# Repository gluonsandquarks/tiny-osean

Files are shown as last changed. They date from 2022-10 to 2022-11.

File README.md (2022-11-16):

# Tiny Osean

Minimal PCB badge based around the ATTiny1616 and a CR2032 battery.

Board in action

This PCB mainly focuses on the capabilities of the manufacturing process to create a non standard PCB with more intricate shapes and patterns. At the end of the day this is more of a wearable/toy PCB rather than a complex application/platform.

DISCLAIMER: I'm not the creator of the artwork, [@oseanworld](https://twitter.com/OseanWorld) is the artist behind the character in the badge.

## Hardware

The board is pretty basic. In total there are 16 components:

- 1 x ATTiny1616: Low power microcontroller.
- 1 x 100nF bypass capacitor.
- 1 x 1uF bypass capacitor.
- 1 x push button.
- 1 x 10k ohm resistor
- 8 x 10 ohm resistors.
- 2 x yellow LEDs.
- 1 x CR2032 battery holder.

If you know what you're doing you could modify the design and add more LEDs, remove bypass caps (they aren't totally necessary with the ATTiny series), etc.

The board has three terminals, two of them are to give power to the board (the _+_ and _-_ pins) and the _D_ terminal is connected to the _PA0_ pin on the ATTiny. This enables the device to be programmed via UPDI.

The design was done through the [svg2shenzhen](https://github.com/badgeek/svg2shenzhen) addon for Inkscape. The _nudeki.svg_ file contains all the layers data for the board. The electrical and PCB design was done in [KiCad v6](https://www.kicad.org/).

Other than that, I think that's it. It's a pretty bare bones design so make of it what you wish. Also the _gerber/_ and _assembly/_ directories contain the necessary files to order and assemble the boards at [jlcpcb.com](https://jlcpcb.com/).

One side note is that the LEDs are mounted in such a way that the light is emitted from the board. The ideal way to mount them is facing down so that the light can shine through the FR-4 and illuminate the eyes more uniformly. With the right tools it's possible to unmount the LEDs and reverse them.

## Firmware

The firmware of the board is located under _firmware/main/_. It contains a simple Arduino sketch but it has the following dependencies:

- [megaTinyCore](https://github.com/SpenceKonde/megaTinyCore): Arduino wrapper for tinyAVR 0/1/2 chips.
- [jtag2updi](https://github.com/SpenceKonde/jtag2updi): UPDI programmer software for Arduino.

Install these dependencies and you'll be able to use an Arduino UNO or similar boards as programmers for the _tiny-osean_ board. If you have any problem with the installation procedure or wiring try looking at [this video](https://www.youtube.com/watch?v=AL9vK_xMt4E).

The _main.ino_ file contains a handful of lighting modes for the board and tries to document them as needed. The programming of the LEDs is pretty straight forward and user friendly, just beware of your logic inside the functions so that the interrupt signal gets processed in a relatively fast way to reduce latency.

## Design Images

### Front View

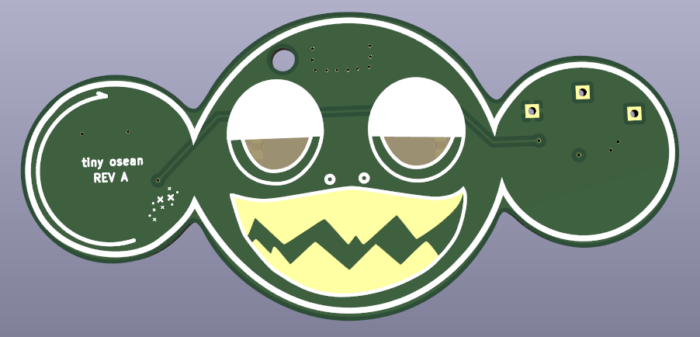
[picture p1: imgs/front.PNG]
3D Front View


### Back View

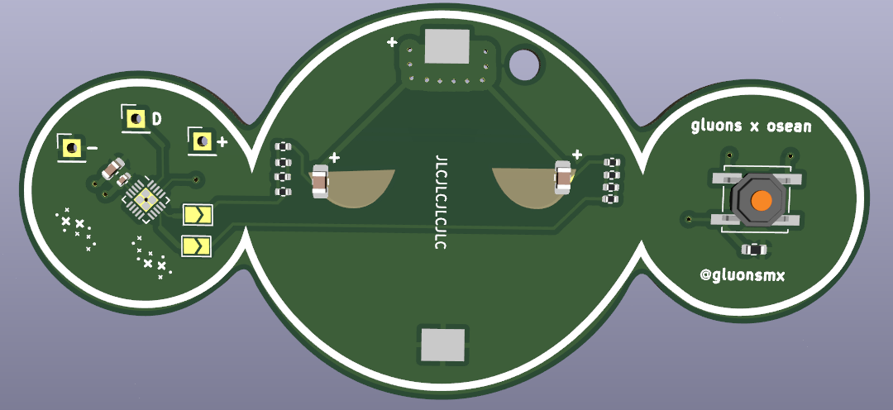
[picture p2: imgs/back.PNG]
3D Back View


### Layers

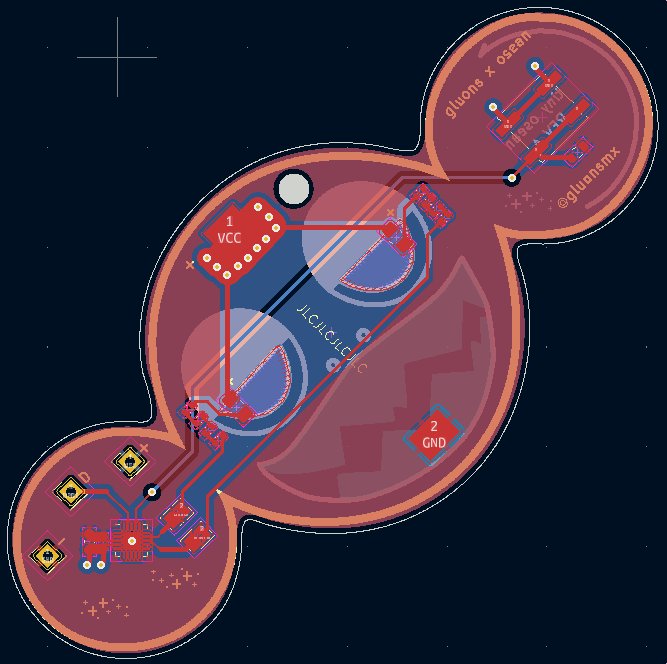
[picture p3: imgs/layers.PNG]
Layers


### Schematic

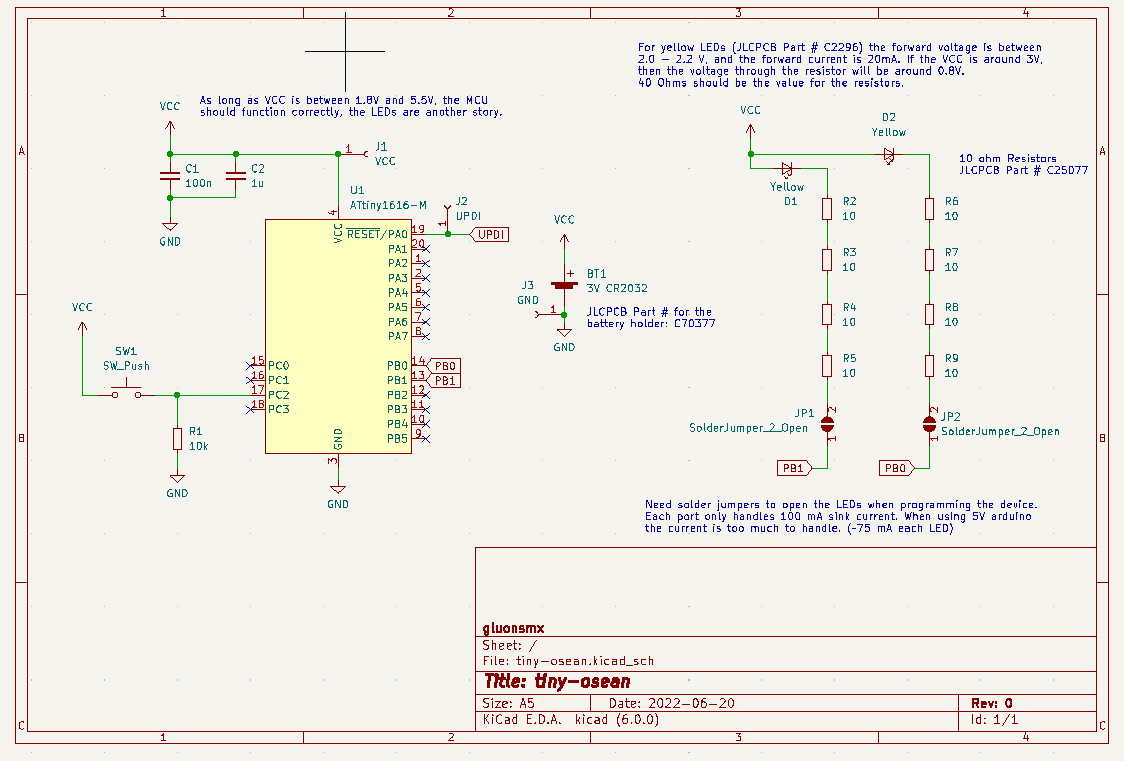
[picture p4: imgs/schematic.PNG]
Schematic


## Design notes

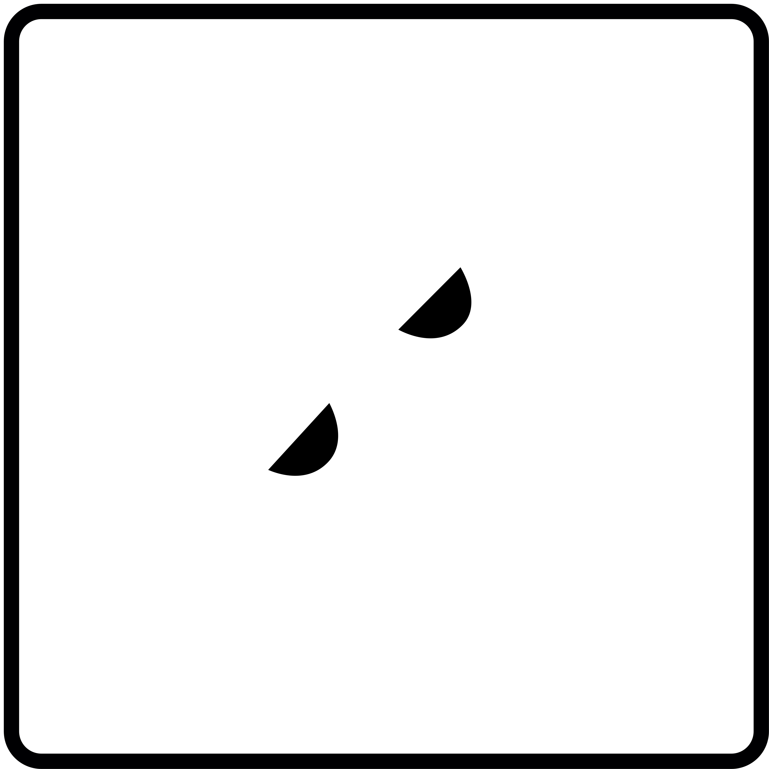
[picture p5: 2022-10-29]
rev b/100mm-osean/.svg2shenzhen-cache/images/F.Mask_g23.png

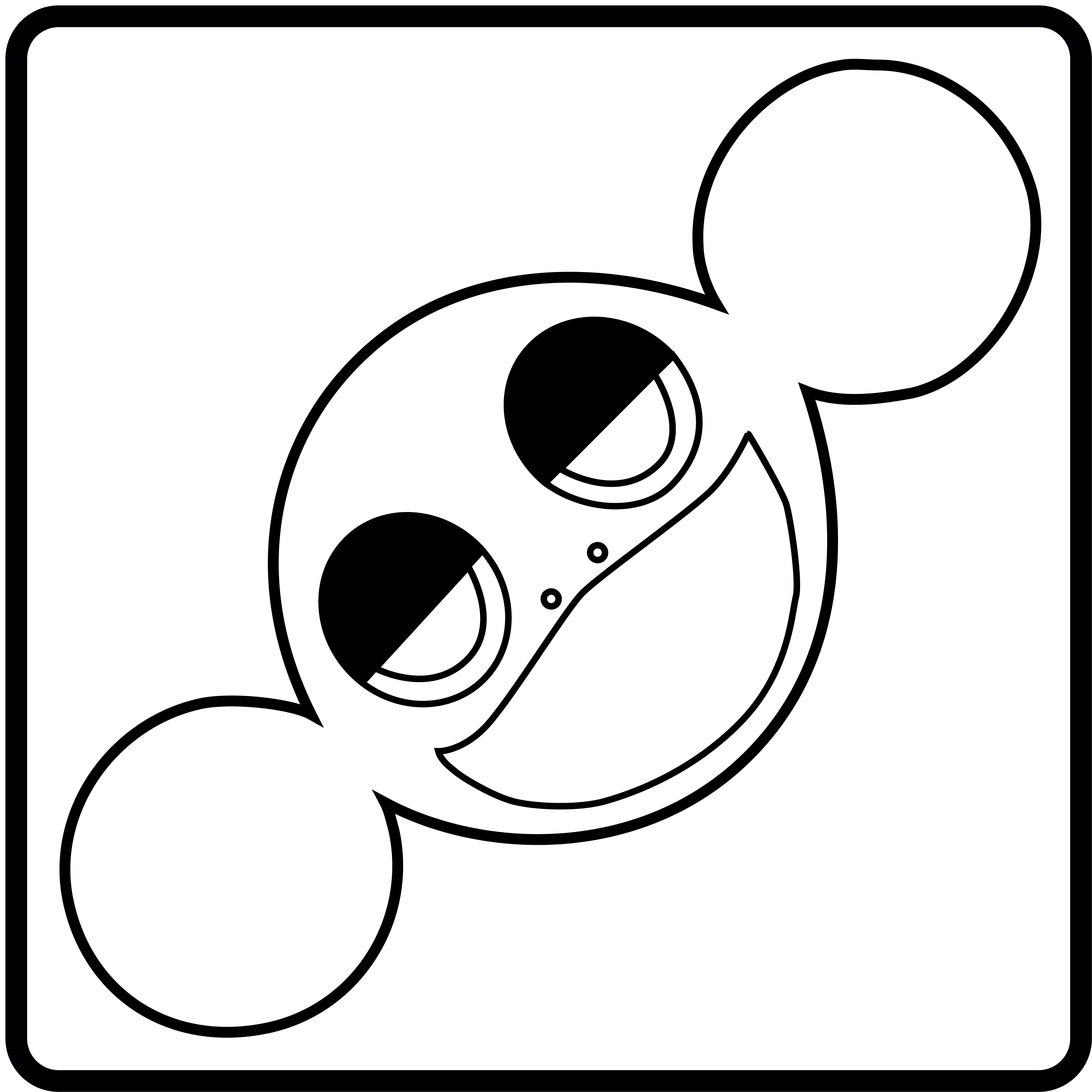
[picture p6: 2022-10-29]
rev b/100mm-osean/.svg2shenzhen-cache/images/B.SilkS_g31.png

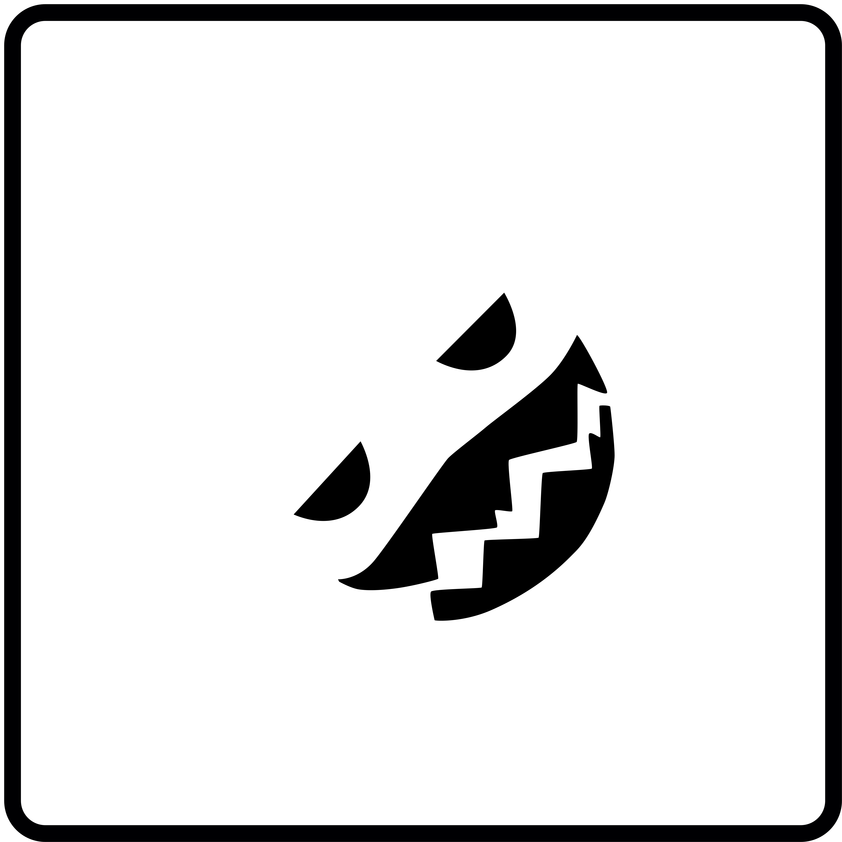
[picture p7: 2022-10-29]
rev b/100mm-osean/.svg2shenzhen-cache/images/B.Mask_g29.png

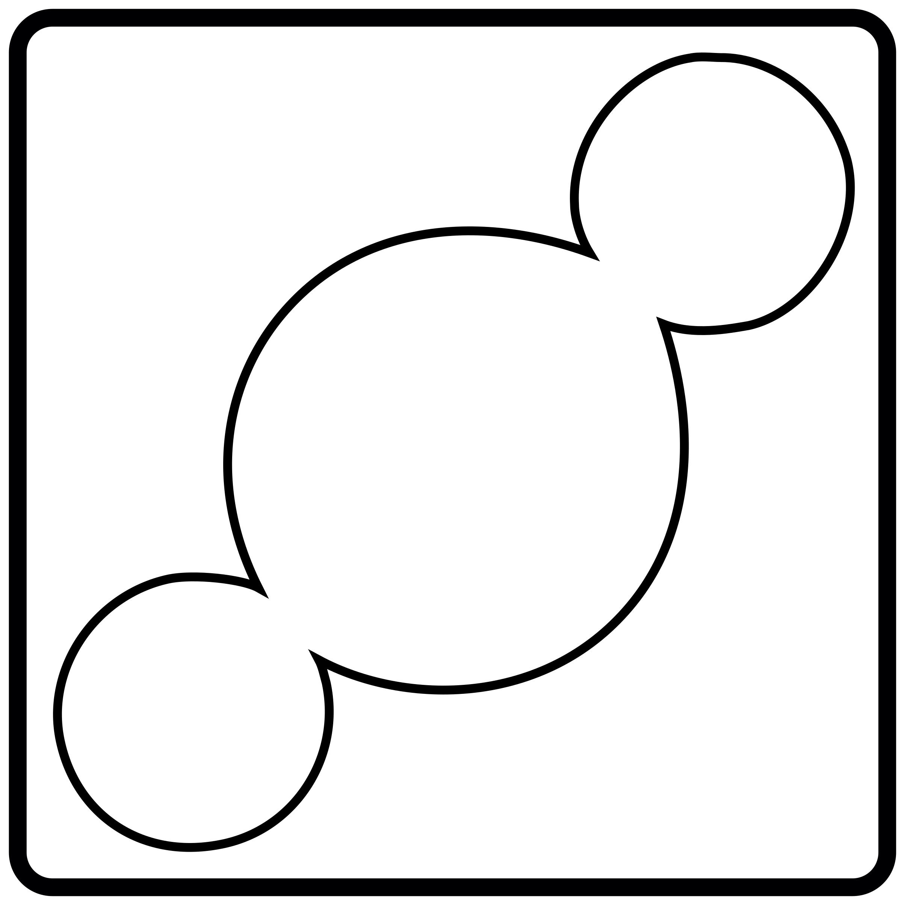
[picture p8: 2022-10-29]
rev b/tiny-osean-footprint/.svg2shenzhen-cache/images/F.SilkS_g25.png

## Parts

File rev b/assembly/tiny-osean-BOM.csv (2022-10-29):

Comment | Designator | Footprint | LCSC
3V CR2032 | BT1 | tiny-osean:CR2032 Holder | C70377
100n | C1 | Capacitor_SMD:C_0402_1005Metric | C307331
1u | C2 | Capacitor_SMD:C_0603_1608Metric | C15849
Yellow | D1,D2 | Capacitor_SMD:C_0805_2012Metric_Pad1.18x1.45mm_HandSolder | C2296
VCC | J1 | Connector_PinHeader_2.54mm:PinHeader_1x01_P2.54mm_Vertical
UPDI | J2 | Connector_PinHeader_2.54mm:PinHeader_1x01_P2.54mm_Vertical
GND | J3 | Connector_PinHeader_2.54mm:PinHeader_1x01_P2.54mm_Vertical
SolderJumper_2_Open | JP1,JP2 | Jumper:SolderJumper-2_P1.3mm_Open_TrianglePad1.0x1.5mm
10k | R1 | Resistor_SMD:R_0603_1608Metric | C25804
10 | R2,R3,R4,R5,R6,R7,R8,R9 | Resistor_SMD:R_0402_1005Metric | C25077
SW_Push | SW1 | Button_Switch_SMD:SW_Push_1P1T_NO_CK_KSC6xxJ | C318884
ATtiny1616-M | U1 | Package_DFN_QFN:VQFN-20-1EP_3x3mm_P0.4mm_EP1.7x1.7mm | C507118

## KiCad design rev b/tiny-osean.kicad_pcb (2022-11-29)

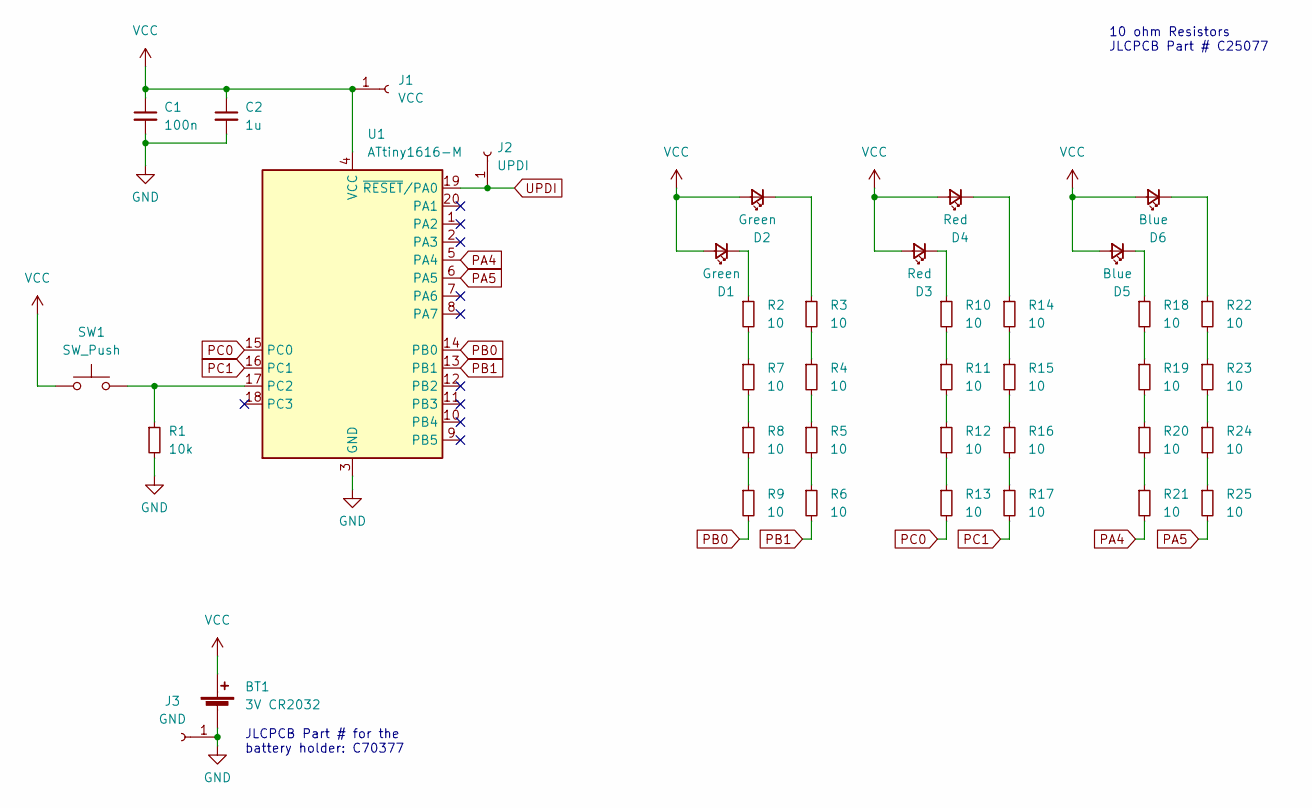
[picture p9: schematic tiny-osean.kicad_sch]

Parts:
BT1: 3V CR2032; CR2032 Holder; LCSC C70377
C1: 100n; C_0402_1005Metric; LCSC C307331
C2: 1u; C_0603_1608Metric; LCSC C15849
D1, D2: Green; C_0805_2012Metric_Pad1.18x1.45mm_HandSolder; LCSC C2296
D3, D4: Red; C_0805_2012Metric_Pad1.18x1.45mm_HandSolder; LCSC C2296
D5, D6: Blue; C_0805_2012Metric_Pad1.18x1.45mm_HandSolder; LCSC C2296
J1: VCC; PinHeader_1x01_P2.54mm_Vertical
J2: UPDI; PinHeader_1x01_P2.54mm_Vertical
J3: GND; PinHeader_1x01_P2.54mm_Vertical
R1: 10k; R_0603_1608Metric; LCSC C25804
R2, R3, R4, R5, R6, R7, R8, R9, R10, R11, R12, R13, R14, R15, R16, R17, R18, R19, R20, R21, R22, R23, R24, R25: 10; R_0402_1005Metric; LCSC C25077
SW1: SW_Push; SW_Push_1P1T_NO_CK_KSC6xxJ; LCSC C318884
U1: ATtiny1616-M; VQFN-20-1EP_3x3mm_P0.4mm_EP1.7x1.7mm; LCSC C507118

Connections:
GND: BT1.2 (-), C1.2, C2.2, J3.1, R1.2, U1.3 (GND), U1.21 (GND)
unnamed: D1.1 (K), R2.1
unnamed: D2.1 (K), R3.1
unnamed: D3.1 (K), R10.1
unnamed: D4.1 (K), R14.1
unnamed: D5.1 (K), R18.1
unnamed: D6.1 (K), R22.1
unnamed: R1.1, SW1.2, U1.17 (PC2)
unnamed: R3.2, R4.1
unnamed: R4.2, R5.1
unnamed: R5.2, R6.1
unnamed: R2.2, R7.1
unnamed: R7.2, R8.1
unnamed: R8.2, R9.1
unnamed: R10.2, R11.1
unnamed: R11.2, R12.1
unnamed: R12.2, R13.1
unnamed: R14.2, R15.1
unnamed: R15.2, R16.1
unnamed: R16.2, R17.1
unnamed: R18.2, R19.1
unnamed: R19.2, R20.1
unnamed: R20.2, R21.1
unnamed: R22.2, R23.1
unnamed: R23.2, R24.1
unnamed: R24.2, R25.1
PA4: R21.2, U1.5 (PA4)
PA5: R25.2, U1.6 (PA5)
PB0: R9.2, U1.14 (PB0)
PB1: R6.2, U1.13 (PB1)
PC0: R13.2, U1.15 (PC0)
PC1: R17.2, U1.16 (PC1)
UPDI: J2.1, U1.19 (~RESET/PA0)
VCC: BT1.1 (+), C1.1, C2.1, D1.2 (A), D2.2 (A), D3.2 (A), D4.2 (A), D5.2 (A), D6.2 (A), J1.1, SW1.1, U1.4 (VCC)

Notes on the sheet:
10 ohm Resistors JLCPCB Part # C25077
JLCPCB Part # for the battery holder: C70377

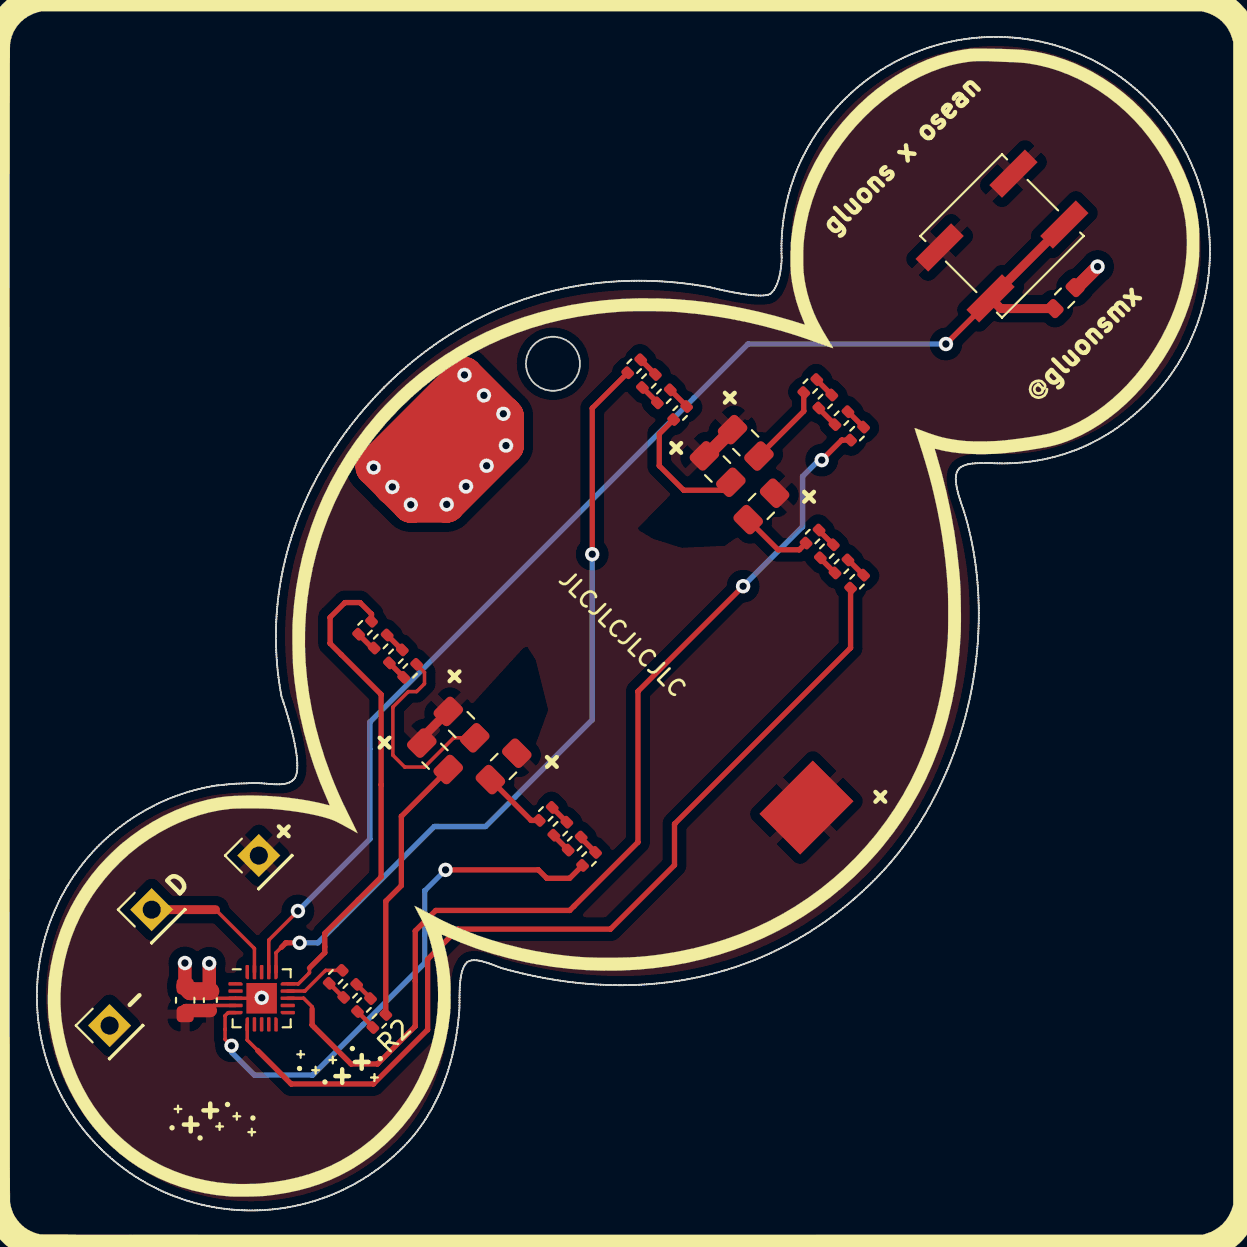
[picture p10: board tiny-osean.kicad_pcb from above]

Board: 2 copper layers, 65.2 x 65.2 mm, 40 parts (0 on the bottom side), 34 nets.

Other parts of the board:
Ref**: Val**; tiny-osean-70

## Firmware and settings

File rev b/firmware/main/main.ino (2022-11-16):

/*
 * This file is part of the tiny-osean project, https://github.com/gluonsandquarks/tiny-osean
 * main.ino - main entry point describing the functionality of the board.
 * This file contains the main logic of the board.
 * 
 * The MIT License (MIT)
 *
 * Copyright (c) 2022 gluons.
 *
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
 * THE SOFTWARE IS PROVIDED "AS IS", WITHOUT WARRANTY OF ANY KIND, EXPRESS OR
 * IMPLIED, INCLUDING BUT NOT LIMITED TO THE WARRANTIES OF MERCHANTABILITY,
 * FITNESS FOR A PARTICULAR PURPOSE AND NONINFRINGEMENT. IN NO EVENT SHALL THE
 * AUTHORS OR COPYRIGHT HOLDERS BE LIABLE FOR ANY CLAIM, DAMAGES OR OTHER
 * LIABILITY, WHETHER IN AN ACTION OF CONTRACT, TORT OR OTHERWISE, ARISING FROM,
 * OUT OF OR IN CONNECTION WITH THE SOFTWARE OR THE USE OR OTHER DEALINGS IN THE
 * SOFTWARE.
 */

#include <avr/sleep.h>            // Power saving library

/* 
 * Pins PB1 and PB0 on the ATTiny1616 are PWM, so analogWrite() should work on them
 * More about how the megaTinyCore lib maps the arduino pins: https://github.com/SpenceKonde/megaTinyCore/blob/master/megaavr/extras/ATtiny_x16.md
 * More about the schematic/pinout of the tiny-osean board: https://github.com/gluonsandquarks/tiny-osean/blob/main/imgs/schematic.PNG
 */
#define LEFT_EYE      PIN_PB1     // PB1
#define RIGHT_EYE     PIN_PB0     // PB0
#define BUTTON        PIN_PC2     // PC2

enum State
{
  ON = 0,
  BREATH_LO,
  BREATH_MID,
  BREATH_HI,
  ALT_LO,
  ALT_MID,
  ALT_HI,
  RUSH,
  RAND_DELAY,
  SOS,
  SMOOTH,
  SLEEP,
  MAX_STATE
};

/* Global variables */
State stat = ON;

/* Forward declarations */
void on();
void breathing(int ms);
void alternating(int ms);
void rush(int ms);
void rand_delay();
void sos();
void smooth();


/* Interrupt Service Routines (ISRs) */
void on_press();
void go_to_sleep();


void on()
{
  digitalWrite(RIGHT_EYE, LOW);
  digitalWrite(LEFT_EYE, LOW);
}

/* Function definitions for the different light shows */

/*
 * @brief Light show that smoothly dims and lights the LEDs through PWM.
 * 
 * @param ms Delay in milliseconds
 * @return Void
 */
void breathing(int ms)
{
  State temp = stat;
  for (int i = 0; i < 256; i++)
  {
    if (temp != stat) { break; }
    analogWrite(RIGHT_EYE, i);
    analogWrite(LEFT_EYE, i);
    delay(ms);
  }
  for (int i = 0; i < 256; i++)
  {
    if (temp != stat) { break; }
    analogWrite(RIGHT_EYE, 255 - i);
    analogWrite(LEFT_EYE, 255 - i);
    delay(ms);
  }
}

/*
 * @brief Light show that alternates both LEDs on/off.
 * 
 * @param ms Delay in milliseconds
 * @return Void
 */
void alternating(int ms)
{
  digitalWrite(RIGHT_EYE, HIGH);
  digitalWrite(LEFT_EYE, LOW);
  delay(ms);
  digitalWrite(RIGHT_EYE, LOW);
  digitalWrite(LEFT_EYE, HIGH);
  delay(ms);
}

/*
 * @brief Light show that alternates both LEDs on/off from dim to bright.
 * 
 * @param ms Delay in milliseconds
 * @return Void
 */
void rush(int ms)
{
  State temp = stat;
  for (float i = 0; i < 128.0F; i += 2.5F)
  {
    if (i >= 64.0F) { i += 3.0F; }
    if (temp != stat) { break; }
    analogWrite(RIGHT_EYE, 255 - i);
    analogWrite(LEFT_EYE, 255);
    delay(ms);
    if (temp != stat) { break; }
    analogWrite(RIGHT_EYE, 255);
    analogWrite(LEFT_EYE, 255 - i);
    delay(ms);
  }
  
  for (int i = 0; i < 5; i++)
  {
    if (temp != stat) { break; }
    digitalWrite(RIGHT_EYE, LOW);
    digitalWrite(LEFT_EYE, HIGH);
    delay(ms * 2);
    if (temp != stat) { break; }
    digitalWrite(RIGHT_EYE, HIGH);
    digitalWrite(LEFT_EYE, LOW);
    delay(ms * 2);
  }

  digitalWrite(RIGHT_EYE, LOW);
  digitalWrite(LEFT_EYE, LOW);
}

/*
 * @brief Light show that lights each LED at random intervals.
 * 
 * @return Void
 */
void rand_delay()
{
  unsigned long timer_1 = 570;
  unsigned long last_timer_1 = 0;
  unsigned long timer_2 = 350;
  unsigned long last_timer_2 = 0;
  State temp = stat;
  while (temp == stat)
  {
    if (millis() - last_timer_1 >= timer_1)
    {
      float multiplier = random(6.0F);
      for (float i = 0; i < 256 * multiplier; i++)
      {
        if (temp != stat) { break ;}
        analogWrite(RIGHT_EYE, (i / multiplier));
      }
      last_timer_1 = millis() * random(500);
    }

    if (millis() - last_timer_2 >= timer_2)
    {
      float multiplier = random(6.0F);
      for (float i = 0; i < 256 * multiplier; i++)
      {
        if (temp != stat) { break; }
        analogWrite(LEFT_EYE, (i / multiplier));
      }
      last_timer_2 = millis() * random(500);
    }
  }
}

/*
 * @brief Light show that emits SOS in morse code.
 * 
 * @param ms Delay in milliseconds
 * @return Void
 */
void sos(int ms)
{
  State temp = stat;
  unsigned long timer = 400;
  unsigned long last_timer = 0;
  for (int i = 0; i < 3; i++)
  {
    if (temp != stat) { break; }
    digitalWrite(RIGHT_EYE, LOW);
    digitalWrite(LEFT_EYE, LOW);
    delay(ms);
    digitalWrite(RIGHT_EYE, HIGH);
    digitalWrite(LEFT_EYE, HIGH);
    delay(ms);
  }

  for (int i = 0; i < 3; i++)
  {
    if (temp != stat) { break; }
    digitalWrite(RIGHT_EYE, LOW);
    digitalWrite(LEFT_EYE, LOW);
    delay(ms * 2);
    digitalWrite(RIGHT_EYE, HIGH);
    digitalWrite(LEFT_EYE, HIGH);
    delay(ms * 2);
  }

  for (int i = 0; i < 3; i++)
  {
    if (temp != stat) { break; }
    digitalWrite(RIGHT_EYE, LOW);
    digitalWrite(LEFT_EYE, LOW);
    delay(ms);
    digitalWrite(RIGHT_EYE, HIGH);
    digitalWrite(LEFT_EYE, HIGH);
    delay(ms);
  }
  last_timer = millis();
  while (temp == stat)
  {
    if (millis() - last_timer >= timer)
    {
      last_timer = millis();
      break;
    }
  }
}

/*
 * @brief Light show that transitions smoothly between both LEDs on board.
 * 
 * @param ms Delay in milliseconds
 * @return Void
 */
void smooth(int ms)
{
  State temp = stat;
  int i = 0;
  int j = 0;

  for (i; i < 256; i++)
  {
    if (temp != stat) { break; }
    if (i > 32) { i += 30; }
    j = i - 8;
    if (j < 0) { j = 0; }
    analogWrite(RIGHT_EYE, 255 - i);
    analogWrite(LEFT_EYE, 255 - j);
    delay(ms);
  }

  i = 255;
  j = 255;
  for (i; i > 0; i--)
  {
    if (temp != stat) { break; }
    if (i > 32) { i -= 30; }
    j = i + 8;
    if (j > 255) { j = 255; }
    analogWrite(RIGHT_EYE, 255 - i);
    analogWrite(LEFT_EYE, 255 - j);
    delay(ms);
  }
  i = 0;
  analogWrite(RIGHT_EYE, 255 - i);
  j = 8;
  for (j; j >= 0; j--)
  {
    if (temp != stat) { break; }
    analogWrite(LEFT_EYE, 255 - j);
    delay(ms);
  }
}

/*
 * @brief ISR called when a button is pressed.
 * 
 * @return Void
 */
void on_press()
{
  stat = State(stat + 1);
  if (stat >= MAX_STATE) { stat = ON; }
}

/*
 * @brief Last mode of the device. Shuts down LEDs and goes to sleep.
 * 
 * @return Void
 */
void go_to_sleep()
{
  digitalWrite(RIGHT_EYE, HIGH);
  digitalWrite(LEFT_EYE, HIGH);
  set_sleep_mode(SLEEP_MODE_PWR_DOWN);
  sleep_enable();
  // TODO: research these parameters for the ATTiny1616. For some reason
  // these guys aren't defined for this MCU. Look into the avr/sleep.h implementation.
  //  byte adcsra = ADCSRA;                             // save ADCSRA
  //  ADCSRA &= ~_BV(ADEN);                             // disable ADC
  cli();                                                 // stop interrupts to ensure the BOD timed sequence executes as required
  //  byte mcucr1 = MCUCR | _BV(BODS) | _BV(BODSE);     //turn off the brown-out detector
  //  byte mcucr2 = mcucr1 & ~_BV(BODSE);
  //  MCUCR = mcucr1;
  //  MCUCR = mcucr2;
  sei();                                                // ensure interrupts enabled so we can wake up again
  sleep_cpu();                                          // go to sleep
  sleep_disable();                                      // wake up here
  //  ADCSRA = adcsra;                                  // restore ADCSRA
}

void setup()
{
  /* Initialize peripherals */
  pinMode(RIGHT_EYE, OUTPUT);
  pinMode(LEFT_EYE, OUTPUT);
  pinMode(BUTTON, INPUT);
  /* Disable floating pins */
  pinMode(PIN_PA1, INPUT_PULLUP);
  pinMode(PIN_PA2, INPUT_PULLUP);
  pinMode(PIN_PA3, INPUT_PULLUP);
  pinMode(PIN_PA4, INPUT_PULLUP);
  pinMode(PIN_PA5, INPUT_PULLUP);
  pinMode(PIN_PA6, INPUT_PULLUP);
  pinMode(PIN_PA7, INPUT_PULLUP);
  pinMode(PIN_PB2, INPUT_PULLUP);
  pinMode(PIN_PB3, INPUT_PULLUP);
  pinMode(PIN_PB4, INPUT_PULLUP);
  pinMode(PIN_PB5, INPUT_PULLUP);
  pinMode(PIN_PC0, INPUT_PULLUP);
  pinMode(PIN_PC1, INPUT_PULLUP);
  pinMode(PIN_PC3, INPUT_PULLUP);
  
  attachInterrupt(digitalPinToInterrupt(BUTTON), on_press, RISING);
}

void loop()
{
  switch(stat)
  {
    case ON:
      on();
      break;
    case BREATH_LO:
      breathing(5);
      break;
    case BREATH_MID:
      breathing(2);
      break;
    case BREATH_HI:
      breathing(0);
      break;
    case ALT_LO:
      alternating(100);
      break;
    case ALT_MID:
      alternating(50);
      break;
    case ALT_HI:
      alternating(25);
      break;
    case RUSH:
      rush(50);
      break;
    case RAND_DELAY:
      rand_delay();
      break;
    case SOS:
      sos(100);
      break;
    case SMOOTH:
      smooth(50);
      break;
    case SLEEP:
      go_to_sleep();
      break;
    default:
      break;
  }
}

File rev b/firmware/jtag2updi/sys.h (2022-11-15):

/*
 * sys.h
 *
 * Created: 02-10-2018 13:07:18
 *  Author: JMR_2
 */

#ifndef SYS_H_
#define SYS_H_

#include <avr/io.h>
#include <string.h>
#include <stdio.h> // for size_t
#include "parts.h"

// Disable the response signature during burst writes to permit faster writes
#define NO_ACK_WRITE

// If using a device based on the HV programmer designed by dlloyd (@Dlloyddev on github), enable that functionality
//#define USE_HV_PROGRAMMING

// Disable the host timeout - this is required for use with avrdude in terminal mode (-t)
// but with this disabled, can get "stuck" if communication with host is interrupted at 115200 baud
// as avrdude on next start will try to communicate at 19200 baud. Reset is required to fix this.
// Potential enhancement - if this is set, while waiting for message from host, ALSO count transitions on the RX pin
// If we see a bunch of transitions, but no received characters, we know the host is using the wrong baud rate, and
// so, switch back to 19200 baud.
//#define DISABLE_HOST_TIMEOUT

// Disable the timeout waiting for response from target. Probably not necessary to set. With this disabled, if the target is expected to respond
// but does not, jtag2updi will get stuck waiting for it.
//#define DISABLE_TARGET_TIMEOUT

// Deduces the NVM version from reading the SIB string. Otherwise, the NVM version is deduced from the size of flash pages.
//#define DEDUCE_NVM_VERSION_FROM_SIB

// this will include the SIB, deduced NVM version, and silicon revision in early responses to SET_DEVICE_DESCRIPTPOR (for SIB and NVM version) and ENTER_PROGMODE (for silicon rev)
//#define INCLUDE_EXTRA_INFO_JTAG


// Auxiliary Macros
#define CONCAT(A,B) A##B				// concatenate
#define XCONCAT(A,B) CONCAT(A,B)		// expand and concatenate
//#define CONCAT3(A,B,C) A##B##C
#if (__AVR_ARCH__ == 103) || (__AVR_ARCH__ == 104)
//We'll call these ones XAVR for purposes of defines, instead of XTINY. This encompasses megaAVR 0-series and DA-series parts

  #define XAVR
  #	define PIN(x) CONCAT(VPORT,x).IN
  #	define PORT(x) CONCAT(VPORT,x).OUT
  #	define DDR(x) CONCAT(VPORT,x).DIR
//	# define PULLUP_ON(x,y) CONCAT(PORT,x).CONCAT3(PIN,y,CTRL)=0x04
//	# define PULLUP_OFF(x,y) CONCAT(PORT,x).CONCAT3(PIN,y,CTRL)=0x04

#else

  #	define PIN(x) CONCAT(PIN,x)
  #	define PORT(x) CONCAT(PORT,x)
  #	define DDR(x) CONCAT(DDR,x)

#endif

/* User Configuration goes up here - the rest down below is defaults that you can override
   or stuff that is hardware specific   */

#if defined(__AVR_ATtiny_Zero_One__)
  // tinyAVR 0-series and 1-series parts
  // 3216, 1604, that kind of thing

  #define LED_PORT A
  #define LED_PIN 7

  // Second LED is used to indicate NVM version, or as an additional debugging aid.
  #define LED2_PORT A
  #define LED2_PIN 6

  // Dickson charge pump pins
  # define cpp PIN3_bm // charge pump power or HV Enable, PA3
  # define cp1 PIN4_bm // charge pump clock 1, PA4
  # define cp2 PIN5_bm // charge pump clock 2, PA5
  # define cps PIN1_bm // charge pump shutdown, PB1

  //USARTDEBUG not practical here because only one UART.
  //#define USE_SPIDEBUG

  //SPIPRESC sets prescaler of SPI clock - it can go *INSANELY* fast, such that very little could keep up with it.

  #define SPIPRESC (SPI_CLK2X_bm|SPI_PRESC1_bm)


#elif defined( __AVR_ATmega_Mighty__ )
  // For ATmega16, 32, ... 128 and the later x4 parts (up to the 1284P).
  // On the ones with two USARTS, you can use USART debugging.
  //
  // Here USART debug output is an option too
  // at least on parts with the second USART
  // You should be able to hit 2MBaud with F_CPU=16000000 and DEBUG_BAUDVAL 0 or 1mbaud with 1 if your serial adapter can't handle that.
  // At 20, though, on classic AVRs, you're out of luck unless you have an adapter that can do 2.5 mbaud...have to go all the way down to 500kbaud (DEBUG_BAUDVAL 4) to divide it to something common.. Good thing almost everyone runs them at 16.
  // #define USE_USARTDEBUG
  // #define DEBUG_BAUDVAL 0




#elif defined (__AVR_ATmega_Mini__) || defined(ARDUINO_AVR_LARDU_328E)
  // For ATmega8/88/168/328 (P, PB) parts
  // Same deal as before/ Remember that the buildin LED is on the same pin as SCK on most boards, so you'll want to cadd LEDs on other pinn, defaults to D2
  // On PB parts can also use second USART. Using the second SPI is not supported.


  //#define USE_SPIDEBUG
  //#define SPIPRESC (0x05)



#elif defined (__AVR_ATmega_Mega__)
  // 2560 and that family, like the ones used on the Arduino Mega
  // Same as the others with extra USARTS, only here you can specify which one if you must
  // #define USE_USARTDEBUG
  // #define DEBUG_USART 2
  // Can even change the host USART if you want


#elif defined (__AVR_ATmega_Zero__ ) || defined( __AVR_DA__)
// 4808, 4809. and the rest of the megaAVR 0-series
// Same as above, pretty much
// big difference here is your specify the name of the peripheral instead of the number, and the target baud rate, because we grab the OSCCAL value per datasheet./
//	#define USE_USARTDEBUG
//	#define DEBUG_USART USART1
//	#define DEBUG_BAUDRATE 2000000UL

  #define LED_PORT A
  #define LED_PIN 7

  //Second LED is used to indicate NVM version, or as an additional debugging aid.
  # define LED2_PORT A
  # define LED2_PIN 6

  // Dickson charge pump pins
  # define cpp PIN0_bm // charge pump power or HV Enable, PC0
  # define cp1 PIN1_bm // charge pump clock 1, PC1
  # define cp2 PIN2_bm // charge pump clock 2, PC2
  # define cps PIN3_bm // charge pump shutdown, PC3

#endif


/* Defaults and hardware-specific stuff 				*/
/* Shouldn't need to change anything here				*/
/* IF you want to override, copy it to the blocks above */


#if defined(__AVR_ATtiny_Zero_One__)
// tinyAVR 0-series and 1-series parts

  # ifndef HVLED_PORT
  #   define HVLED_PORT A
  # endif

  # ifndef HVLED_PIN
  #   define HVLED_PIN 6
  # endif

  # ifndef UPDI_PORT
  #   define UPDI_PORT B
  # endif

  # ifndef UPDI_PIN
  #   define UPDI_PIN 0
  # endif

  # ifndef LED_PORT
  #   define LED_PORT A
  # endif

  # ifndef LED_PIN
  #   define LED_PIN 7
  # endif

  # ifndef HOST_USART
  #   define HOST_USART USART0
  # endif

  # ifndef HOST_TX_PORT
  #   define HOST_TX_PORT B
  # endif

  # ifndef HOST_TX_PIN
  #   define HOST_TX_PIN 2
  # endif

  # ifndef HOST_RX_PIN
  #   define HOST_RX_PIN 3
  # endif

#elif defined( __AVR_ATmega_Mighty__ )
// For ATmega16, 32, ... 128 and the later x4 parts (up to the 1284P).

  #	ifndef HOST_USART
  #		define HOST_USART 0
  #	endif

  #	ifndef UPDI_PORT
  #		define UPDI_PORT C
  #	endif

  #	ifndef UPDI_PIN
  #		define UPDI_PIN 7
  #	endif

  #	ifndef LED_PORT
  #		define LED_PORT B
  #	endif

  #	ifndef LED_PIN
  #		define LED_PIN 7
  #	endif


#elif defined (__AVR_ATmega_Mini__) || defined(ARDUINO_AVR_LARDU_328E)
// For ATmega8/88/168/328 (P, PB) parts
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

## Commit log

2022-10-29 Final Rev A
    [tiny-osean-BOM.csv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]
2022-11-22 started rev b
    [tiny-osean-BOM.csv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]
2022-11-29 finished rev b in one night cause discounts dont last forever
    [tiny-osean.kicad_pcb, tiny-osean.kicad_sch]
